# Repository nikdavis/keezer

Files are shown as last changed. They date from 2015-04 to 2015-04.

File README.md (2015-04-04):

## Nik's chest freezer (KEEZER) project

This project includes
- Schematics, board file
- MCU code (Arduino based)
- Archaic (likely-broken) web interface

It is a snapshot of where I left this project. I'm currently looking for the schematic/board files across my HDDs. I don't recall if they were created with EAGLE or Altium. To be remembered...

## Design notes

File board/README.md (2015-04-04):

## Schematic, board and art
This an Altium Designer based project. You should be able to load it up. This includes the schematic, board, and last generated art (Gerbers and NC Drill files).

Does it work? Yes.

Todo:
- [ ] Add surge protection and snubbing to solid state relay (mine blew after a few months). There's a fantastic back-to-back zener diode package that is made just for this, but I can't recall the brand name!
- [ ] Remember the name of back-to-back zener diode package
- [ ] Scale larger, add better board mount holes
- [ ] Make room for proper heatsink on SSR (or document if no change needed)

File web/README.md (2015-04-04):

## What is this?!

This was an archaic live graph of the temperature. It requires a locally running:
- apache server with modpython (or other flavor)
- mysql server
- keezer board with usb connected locally
I think that was it.

## What files do what?
- ```average_temp.py```
  - Used to find average (integrated) temp to study keezer's over/undershoot
- ```index.html```
  - View live temp graph
- ```pulltemp.py```
  - Server-side python script to dump X # of reading in JSON
- ```readtemp.py```
  - A (really basic) background script to read temps from the keezer board

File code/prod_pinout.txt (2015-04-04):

temp controller...

arduino pinout:

DISP_PWM_PIN 10 -- PB2
MENU_PIN 2 -- PD2
UP_PIN 9 -- PB1
DOWN_PIN 8 -- PB0
RELAY_PIN 13 -- PB5
TENS_FET 12 -- PB4
ONES_FET 11 -- PB3
(driven high, duh)
TEMP_SENSOR 3 -- PD3

BCD PINS

B0 -> 4 -- PD4
B1 -> 5 -- PD5
B2 -> 6 -- PD6
B3 -> 7 -- PD7

CHANGED RELAY PIN so programming won't interfere
NEW RELAY PIN -- PC3

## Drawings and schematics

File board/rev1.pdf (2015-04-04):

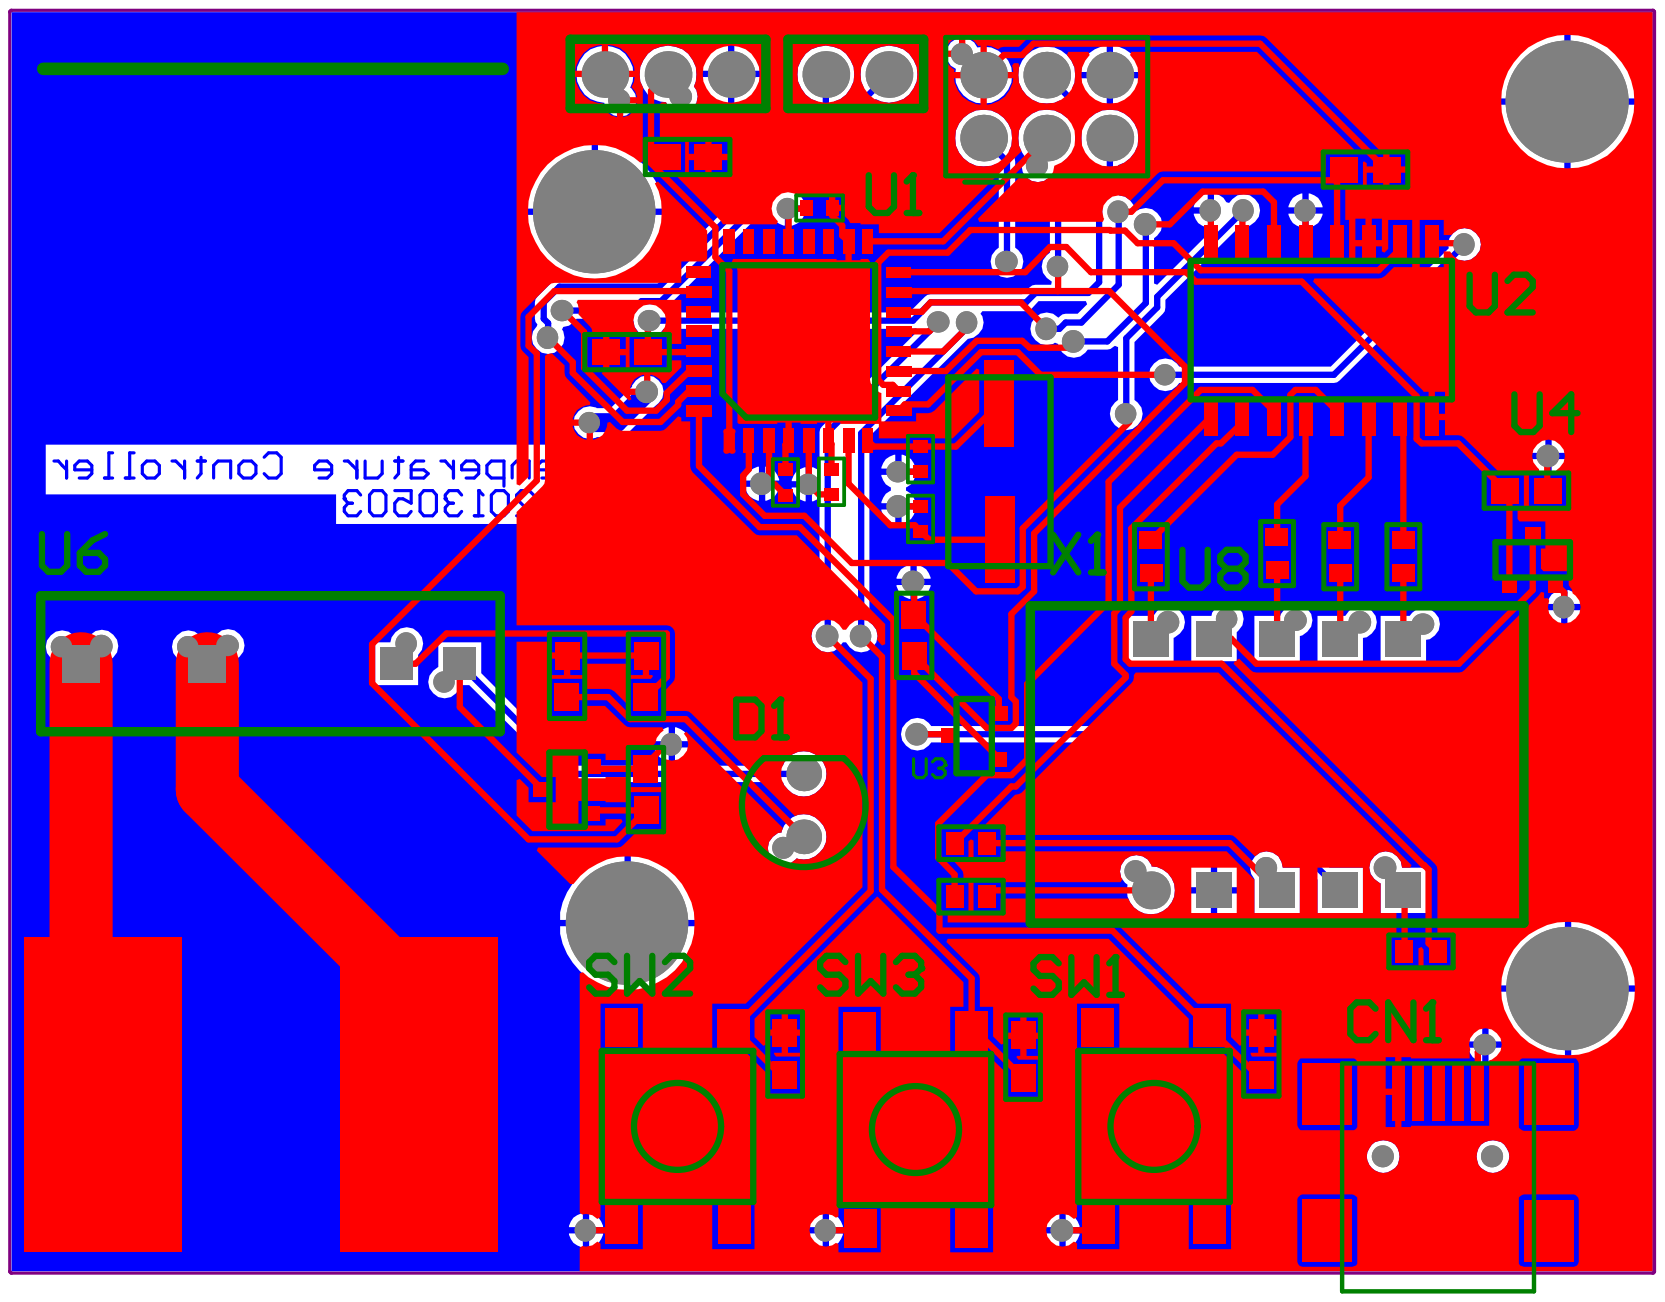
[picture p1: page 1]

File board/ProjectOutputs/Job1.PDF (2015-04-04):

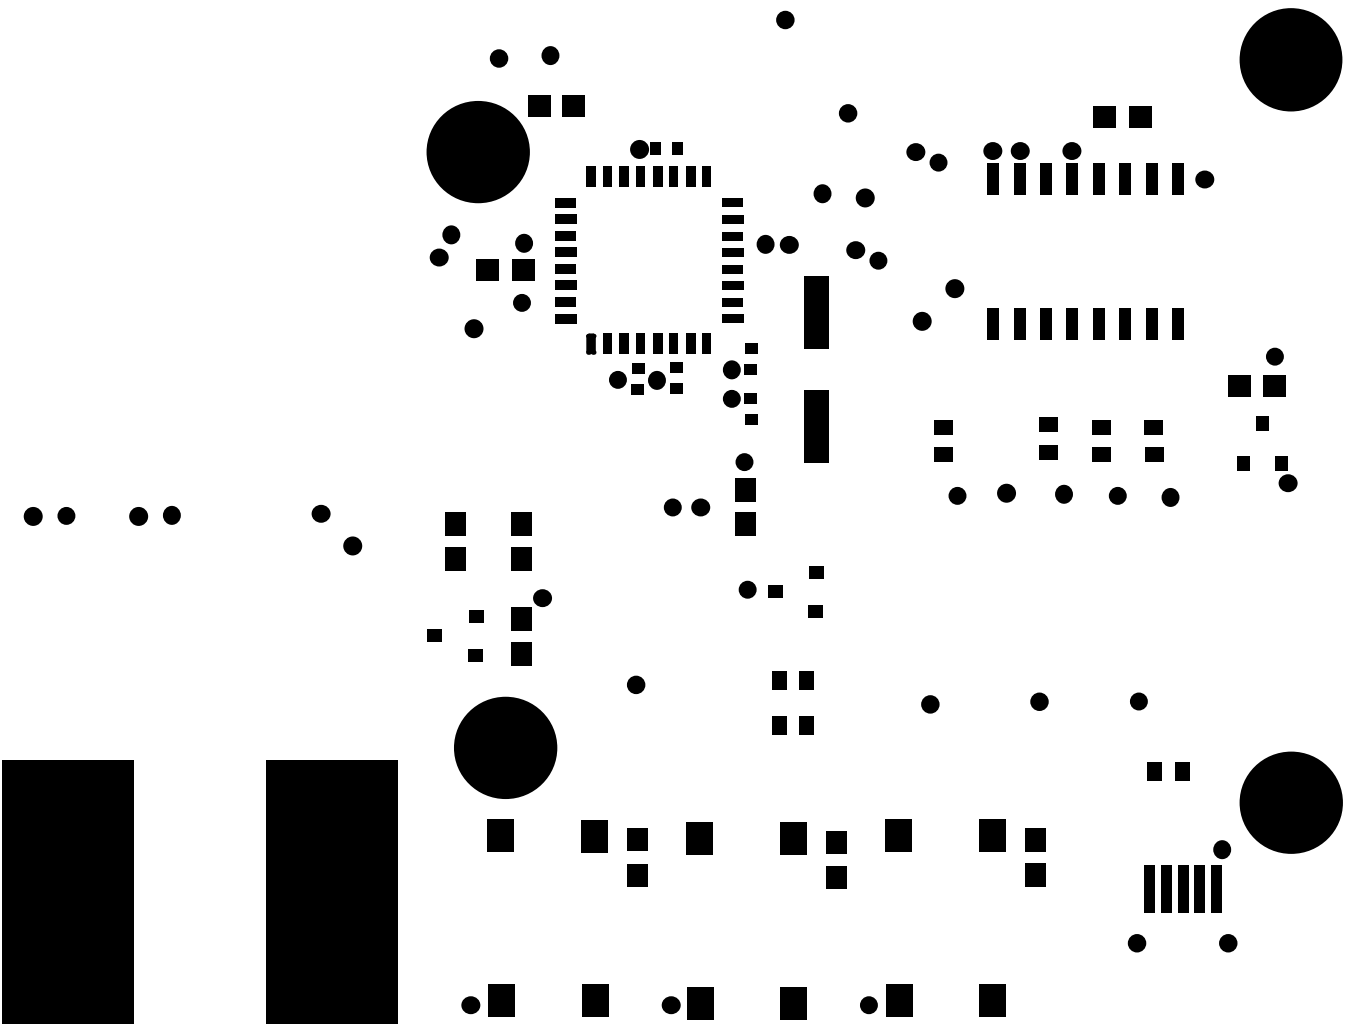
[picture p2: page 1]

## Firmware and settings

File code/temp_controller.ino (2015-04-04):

#include <OneWire.h>

// Pin defines
#define DISP_PWM_PIN 10
#define MENU_PIN 2
#define UP_PIN 9
#define DOWN_PIN 8
#define RELAY_PIN 17
#define SENSOR_PIN 3

// Constant defines
#define START_TARGET_TEMP 65       // initial goal temperature
#define MENU_BUTTON_HOLD_TIME 3    // in seconds
#define MAX_TEMP_SETTING 75
#define MIN_TEMP_SETTING 20
#define TEMP_OVERSHOOT 3           // How high past target we will let temp rise
#define TEMP_UNDERSHOOT 1          // How far to cool under target temp
#define MIN_COMPRESSOR_DOWNTIME 300  // Have to wait at least 5 minutes (300 seconds) before turning compressor on again
#define PRINT_INTERVAL 30          // time in seconds

// Relay states
#define RELAY_ON HIGH
#define RELAY_OFF LOW

OneWire ds(SENSOR_PIN);  // One wire data pin

// Housekeeping variables
int digit, toggle, tens, ones, intensity;

// Important variables
int targetTemperature;

// Currently pins 4-10
// pin wise, top right to top left, bottom right to bottom left
int BCD_PINS[] =
		{	4,	// 0
			5,	// 1
			6,	// 2
			7};	// 3

// Function prototypes
int SET_BCD_DRIVER( int, int []);
void setDisplayIntensity(int);
void setDisplay(int);
int targetTempMenu(void);
float getTemperature(void);



void setup(void) {
  
  // Housekeeping variables
  digit = 0;
  toggle = 0;
  intensity = 50;  // 7-segment PWM intesity, out of 255
  
  setDisplay(88);
  setDisplayIntensity(intensity);
  
  // Important variables
  targetTemperature = START_TARGET_TEMP;
  
  pinMode(RELAY_PIN, OUTPUT);
  digitalWrite(RELAY_PIN, RELAY_OFF);    // Make sure relay is OFF
  
  pinMode(DISP_PWM_PIN, OUTPUT);
  pinMode(MENU_PIN, INPUT);
  pinMode(UP_PIN, INPUT);
  pinMode(DOWN_PIN, INPUT);
  pinMode(11, OUTPUT);
  pinMode(12, OUTPUT);
  
  Serial.begin(9600);
  
  for(int i = 0; i < 4; i++) {
    pinMode(BCD_PINS[i], OUTPUT);
    digitalWrite(BCD_PINS[i], HIGH);
  }
  
  // *************************
  //  SET UP INTERRUPTS
  // *************************
  //
  cli();//stop interrupts
  
  // Set up mode pin interrupt on INT1
  // must check SREG I-flag for INT1
  // set interrupt mask as well
  
  // Set ISC01, ISC00 to 0 for low level INT0 interrupt. Don't affect ISC10, 11
  EICRA &= 0xFF ^ (1 << ISC00);
  EICRA &= 0xFF ^ (1 << ISC01);
  
  // Set external interrupt mask to enable INT0, disable INT1
  EIMSK &= 0;
  EIMSK |= (1 << INT0);
  
  //set timer2 interrupt at 2kHz
  TCCR2A = 0;// set entire TCCR2A register to 0
  TCCR2B = 0;// same for TCCR2B
  TCNT2  = 0;//initialize counter value to 0
  // set compare match register for 8khz increments
  OCR2A = 249;// = (16*10^6) / (8000*8) - 1 (must be <256)
  // turn on CTC mode
  TCCR2A |= (1 << WGM21);
  // Set CS11 bit for 8 prescaler
  TCCR2B |= (1 << CS11); // | (1 << CS10);   
  // enable timer compare interrupt
  TIMSK2 |= (1 << OCIE2A);
  sei();//allow interrupts

}



void loop(void) {

  int temp = 0;
  float tempFloat = 0.0;  // Set it low so we won't turn on until we get a real temp
  int freezerState = 0;
  int printInterval = PRINT_INTERVAL;          // print every XX seconds
  unsigned long lastPrint = 0;
  unsigned long timeSinceLastShutoff = 0;      // Won't allow compressor to turn on for the first 300 seconds (5 minutes) of startup, and every 5 after freezer shuts off.  Timed in seconds.
  unsigned long lastCompressorShutoff = 0;    // Time in millis() that the freezer last shut off
  
  digitalWrite(RELAY_PIN, RELAY_OFF);
  
  while(1) {
    tempFloat = getTemperature();
    temp = (int) (tempFloat + 0.5);
    setDisplay(temp);
  
    if ((freezerState == 0) && (temp >= (targetTemperature + TEMP_OVERSHOOT)) && (timeSinceLastShutoff > MIN_COMPRESSOR_DOWNTIME)) {
      freezerState = 1;
      digitalWrite(RELAY_PIN, RELAY_ON);  // Turn it on
      //Serial.println("FREEZER ON");
    }
    else if ( (freezerState == 1) && (temp <= (targetTemperature - TEMP_UNDERSHOOT)) ) {
      freezerState = 0;
      digitalWrite(RELAY_PIN, RELAY_OFF); // Turn it off
      //Serial.println("FREEZER OFF");
      
      // Update compressor shutoff time
      lastCompressorShutoff = millis();
    }
  
    delay (25);
    timeSinceLastShutoff =  ( millis() - lastCompressorShutoff ) / 1000;    // Time in seconds
    delay (100);
    
    if( ((millis() - lastPrint) / 1000) >= printInterval ) {
      Serial.print(targetTemperature);
      Serial.print(",");
      Serial.print(tempFloat);
      Serial.print(",");
      //Serial.print((millis() - lastPrint) / 1000);
      //Serial.print(",");
      if(freezerState) {
        Serial.println("On");
      } else {
        Serial.println("Off");
      }
      lastPrint = millis();
    }
    
    // In case millis overflows
    if(millis() < lastCompressorShutoff) {
      // We've overflowed
      lastCompressorShutoff = 0;
      lastPrint = 0;
    }
  }

}



// Interrupt for display muliplexing
ISR(TIMER2_COMPA_vect){//timer1 interrupt 8kHz toggles pin 9
//generates pulse wave of frequency 8kHz/2 = 4kHz (takes two cycles for full wave- toggle high then toggle low)
  cli();
  if (toggle){
    digitalWrite(11, LOW);
    SET_BCD_DRIVER(tens, BCD_PINS);
    digitalWrite(12, HIGH);
    toggle = 0;
  }
  else{
    digitalWrite(12, LOW);
    SET_BCD_DRIVER(ones, BCD_PINS);
    digitalWrite(11, HIGH);
    toggle = 1;
  }
  sei();
}


// Interrupt for menu button press
ISR(INT0_vect){
  // Critical zone
  cli();
  EIMSK &= 0;  // 0b 1111 1110
  sei();
  int holdTime = (MENU_BUTTON_HOLD_TIME * 1000) / 10;
  int delayElapsed = 0;    // in tens of milliseconds, or centiseconds
  int toggleDisplay = 1;
  int displayOld = (tens * 10) + ones;
  
  // Set display to 88 to acknowledge button press
  setDisplay(88);
  
  // Disable this interupt for the time being
  // DelayElapsed will overflow after 5.5 minutes or so
  while(digitalRead(MENU_PIN) == LOW) {
    delay(10);
    // Blink the digits every 250 ms if we've crossed the required hold time
    // but stay in this loop.
    if(delayElapsed > holdTime) {
      if(delayElapsed % 25 == 0) {
        toggleDisplay = (toggleDisplay + 1) % 2;
        if(toggleDisplay) {
          setDisplayIntensity(intensity);  // Turn on
        } else {
          setDisplayIntensity(0);          // Turn off
        }
      }
    }
    ++delayElapsed;
  }
  
  // Make sure display gets turned back on
  setDisplayIntensity(intensity);
  
  // The button has been let go, if time threshold reached go to menu procedure
  if(delayElapsed > holdTime) {
    targetTempMenu();
  }
  
  // Set display back to original output before interrupt
  setDisplay(displayOld);
  
  // Critical zone, renable this input then exit
  cli();
  EIMSK |= (1 << INT0);
  sei();
}


// Actually takes the ones/tens numbers and updates
// the 4511 BCD to 7 segment driver with single BCD digit.
int SET_BCD_DRIVER( int number, int PINS[]) {
  // Find constituent numbers
  int i, bcd_bit;
  bcd_bit = 0;
  
  // Check that number can fit on one seven segment display
  if (number > 10 || number < 0) {
    return -1;
  }
  
  // Set each pin based off BCD digit
  for(i = 0; i < 4; i++) {
    bcd_bit = number & 1;       // Grab lowest bit
    if(bcd_bit) {
      digitalWrite(PINS[i], HIGH);
    }
    else {
      digitalWrite(PINS[i], LOW);
    }
    number = number >> 1;     // Shift segments
  }
  
  return 1;
}


// Sets the PWM intensity of the 7 segment display, 0 - 255.
void setDisplayIntensity(int pwm) {
  if(pwm < 0) {
    pwm = 0;
  }
  if(pwm > 255) {
    pwm = 255;
  }
  analogWrite(DISP_PWM_PIN, pwm);
}


// Splits the number into 10s and 1s and pushes output
// to the display
void setDisplay(int num) {
  if(num < 100 && num >= 0) {
    tens = num / 10;
    ones = num % 10;
  }
}


// Menu for setting target temperature.  Button presses
// are asserted LOW.  Would be nice to save the temperature
// somewhere static in case of power outage.
int targetTempMenu(void) {
  int tempTarget =  targetTemperature;
  int pressDelay = 3;             // 3 ms
  setDisplay(tempTarget);
  
  // Must press menu pin again to exit menu
  while(digitalRead(MENU_PIN) == HIGH) {
    if(digitalRead(UP_PIN) == LOW) {
      if(tempTarget < MAX_TEMP_SETTING) {
        setDisplay(++tempTarget);
      }
      while(digitalRead(UP_PIN) == LOW) {
        delay(pressDelay);
      }
    }
    else if(digitalRead(DOWN_PIN) == LOW) {
      if(tempTarget > MIN_TEMP_SETTING) {
        setDisplay(--tempTarget);
      }
      while(digitalRead(DOWN_PIN) == LOW) {
        delay(pressDelay);
      }
    }
    
    targetTemperature = tempTarget;
  }
  
  // Catch exit button press so we don't restart interrupt
  while(digitalRead(MENU_PIN) == LOW) {
    delay(pressDelay);
  }
  
  // Blink the chosen temperature on the way out as affirmation
  for(int i = 0; i < 4; i++) {
    setDisplayIntensity(0);
    delay(250);
    setDisplayIntensity(intensity);
    delay(250);
  }
}

float getTemperature(void) {
  byte i;
  byte present = 0;
  byte type_s;
  byte data[12];
  byte addr[8];
  float celsius, fahrenheit;
  int temp_int;
  
  if ( !ds.search(addr)) {
    //Serial.println("No more addresses.");
    //Serial.println();
    ds.reset_search();
    delay(250);
  }

  if (OneWire::crc8(addr, 7) != addr[7]) {
      //Serial.println("CRC is not valid!");
  }

  ds.reset();
  ds.select(addr);
  ds.write(0x44);         // start conversion, with parasite power on at the end
  
  delay(1000);     // maybe 750ms is enough, maybe not
  // we might do a ds.depower() here, but the reset will take care of it.
  
  present = ds.reset();
  ds.select(addr);    
  ds.write(0xBE);         // Read Scratchpad

  for ( i = 0; i < 9; i++) {           // we need 9 bytes
    data[i] = ds.read();
  }

  // convert the data to actual temperature

  unsigned int raw = (data[1] << 8) | data[0];
  if (type_s) {
    raw = raw << 3; // 9 bit resolution default
    if (data[7] == 0x10) {
      // count remain gives full 12 bit resolution
      raw = (raw & 0xFFF0) + 12 - data[6];
    }
  } else {
    byte cfg = (data[4] & 0x60);
    if (cfg == 0x00) raw = raw << 3;  // 9 bit resolution, 93.75 ms
    else if (cfg == 0x20) raw = raw << 2; // 10 bit res, 187.5 ms
    else if (cfg == 0x40) raw = raw << 1; // 11 bit res, 375 ms
    // default is 12 bit resolution, 750 ms conversion time
  }
  
  celsius = (float)raw / 16.0;
  fahrenheit = celsius * 1.8 + 32.0;
  //temp_int = fahrenheit + 0.5;
  
  // Set BCD digits, background interrupt will send to display
  setDisplay(temp_int);
  
  return fahrenheit;    // return the rounded integer temperature
}

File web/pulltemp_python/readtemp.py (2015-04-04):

import serial, json, random, time, sys
import MySQLdb as mdb

ard = serial.Serial('/dev/ttyUSB0', 9600)
db = mdb.connect("localhost", "root", "sunshine", "keezer_temp")
cur = db.cursor()

while 1:
	line = ard.readline()
	print line
	#line = str(temp) + "," + str(setting) + ",\"Off\"" #\r\n"	
	line = line.rstrip('\r\n ').split(',')
	line[2] = "'" + line[2] + "'"
	line = ','.join(line)
	query = "insert into readings (target, temp, relayState, timestamp) values ("
	query += line + "," + str(time.time()) + ");"
	print query
	cur.execute(query)
	db.commit()
	time.sleep(1)

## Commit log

2015-04-04 Adding all the files
    [data.csv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]
2015-04-04 Found board project!
    [main.SchDoc, rev1.PcbDoc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]
2015-04-04 Board project readme.
2015-04-04 Removed unnecessary sketches. Some may be interesting if you want to checkout prior commit.
    [rev1.GBL, rev1.GBP, rev1.GM1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]
2015-04-04 Board readme.
